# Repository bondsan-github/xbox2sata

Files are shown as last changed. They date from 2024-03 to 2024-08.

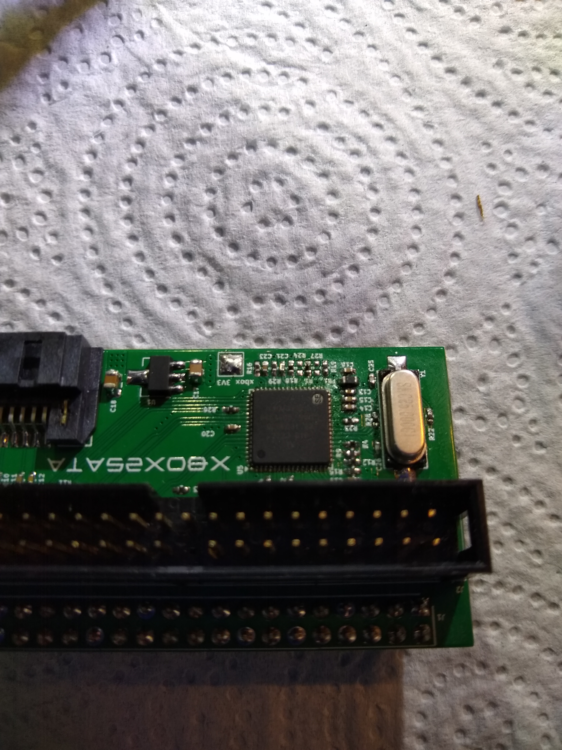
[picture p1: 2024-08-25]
Images/IMG_20240824_140959480.jpg

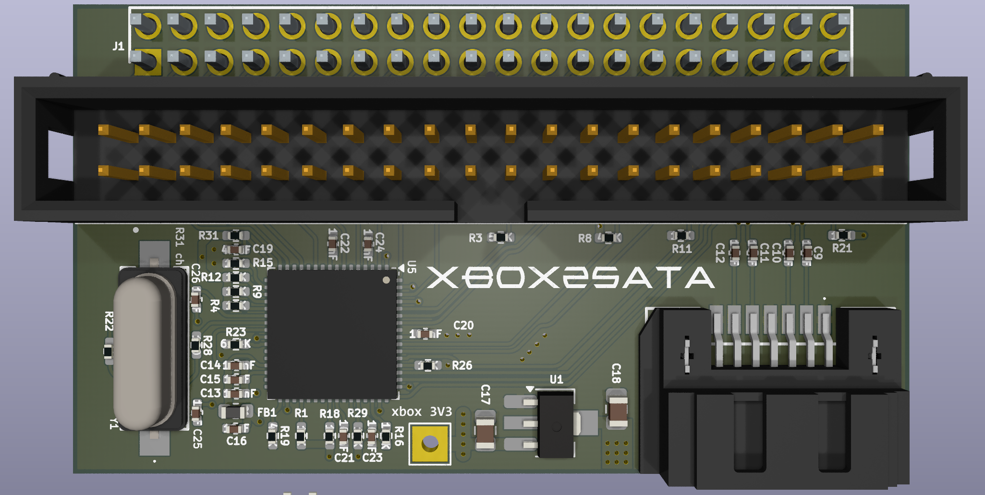
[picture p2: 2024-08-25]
Images/3d_render.png

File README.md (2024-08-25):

Aim
===
- Create a IDE to SATA bridge PCB with pass-through socket for XBox DVD cable.
- !3d render[3d render](/Images/3d_render.png)

Motivation
==========
- Remove the need for a 80 wire IDE cable
- Use existing IDE cable for DVD drive

Completed
=========
- Unverified schematic of Startech IDE2SATA pcb
- Startech IDE2SATA layer scans and annotations in GIMP .xcf image format.

To do
=====
Measure components;
- L1

- Find suitable 3V3 and ground points to tap on XBox motherboards
- Measure available space inside XBox under DVD drive.
  - there is/are a radial capacaitor/s close to the IDE header
    - I would like to not make a hole in the PCB for matched IDE to IDE routing lengths
    - The capactor/s have enough leg legnth to pull up and lay flat

- Can xbox ide connection be directly connected to DVD connection?
  - Simular how a IDE cable does?
  - IDE cable does have CSEL tied hi or low depending on device?
- Can LED circuit be removed? Is it for HDD activity?
- CSEL cable selection can be fixed as DVD will always be device 0 (slave) and SATA device 1 (master)?
- What capacitors are required for power input from xbox motherboard?

Requirements
============
- Marvell 88SA8052 - NNC2 IC
  -  PATA/ATAPI to SATA bridge chip W/ATAPI, 3 GBps SATA
     -  64 pin
     -  package: PQFN50P900X900X90-65
  - 1V2 Voltage regulator for Marvel IC Vdd
  - 3V3 for Marvel Vddio 
  - 25Mhz crystal oscillator
  - CNFG0,1,2 setup
  - T0,1,2,3,4,5,6,7,8 setup
  - will require 3V3 and ground solder points from all six motherboard revisions
    - 1.0 , 1.1 , 1.2 , 1.3 , 1.4 , 1.6/b

- xbox motherboard IDE socket
- DVD drive IDE header
- SATA to HDD/SATA socket

Desirables
==========
- Marvell 88SA8052 datasheet
- Connect pcb directly to xbox ide header on motherboard.
- Use motherboard 3V3 reducing one power regulator.
- Use existing IDE cable from pcb to dvd drive.
  - Cut or roll second connector behind dvd drive.
- Use power from existing molex connector to HDD/SSD.
  
Software used
=============
- GIMP 2.99.18 development release
- KiCad Schematic Editor 8.0.1
- Proteus 8.15 SP1
  
Sources
=======
- https://www.psdevwiki.com/ps3/88SA8040-TBC1
- https://consolemods.org/wiki/Xbox:Versions
- https://www.ioi.com.tw/products/proddetail.aspx?CatID=101&HostID=2010&DeviceID=3002&ProdID=1010114
- https://en.wikipedia.org/wiki/Parallel_ATA
- https://www.startech.com/en-gb/hdd/ide2sat2

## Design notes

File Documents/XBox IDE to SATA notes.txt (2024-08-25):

JM20330
88SA8040

http://www.dc-swat.ru/forum/printthread.php?tid=2482
Code:
pin 33 - T0          vendor ID (need PD 10 kOm)
pin 34 - T1          vendor ID/SATA LED# (need PU 10 kOm to VDD2 (3V3))
pin 35 - T2          PD: disable SSC     PU: enable SSC (int PD)
pin 36 - T3          clock speed     PD: 20MHz     PU: 25MHz    
pin 37 - T4          clock speed (need PD 10 kOm)
pin 38 - T5          fix UDMA mode     PD: monitor set feature     PU: fixes its UDMA mode
pin 39 - T6          power mode     PD: disable     PU: enable
pin 40 - T7          SATA mode     PD: 1.5 Gbps     PU: 3.0 Gbps
pin 52 - T8          SIGNATURE FIS     PD: transformer from registers     PU: force bit4 to 1

pin 18          pin 19          pin 20
CNFG0           CNFG1           CNFG2

  PD              PD               PD          Device mode 100 MB/s
  PU              PD               PD          Device mode 133 MB/s
  PD              PU               PD          Device mode 150 MB/s
  PD              PU               PU          Host mode 150 MB/s

*PD - pool down (connect to GND over resistor 10 kOm)
*PU - pool up (connect to VCC2(3.3 V) over resistor 10 kOm)

FB1 psdevwiki BLM11P600S; no longer manufactured, replaced with BLM18PG600SN1D

https://www.mouser.co.uk/ProductDetail/Murata-Electronics/BLM18PG600SN1D?qs=LbqjZSvnDsxC2SXhhViR%252BA%3D%3D

IDE to Marvell IC
=================
1  (RESET-) 16
2  GND
3  (DD7)  15
4  (DD8)  14
5  (DD6)  13
6  (DD9)  12
7  (DD5)  11
8  (DD10) 10
9  (DD4)  7
10 (DD11) 6
11 (DD3)  5
12 (DD12) 3
13 (DD2)  2
14 (DD13) 1
15 (DD1)  64
16 (DD14) 63
17 (DD0)  62
18 (DD15) 61
19 GND
20 KEY PIN
21 (DMARQ) 60
22 GND
23 (DIOW-) 59
24 GND
25 (DIOR-) 58
26 GND
27 (IORDY) 55
28 (CSEL) -> jumpers pin 1 & pin 2 -> R14 -> 3V3 
29 (DMACK-) 54
30 GND
31 (INTRQ) 53
32 (IOCS16) -> R13 -> GND
33 (DA1) 51
34 (PDIAG-) 
35
36
37
38
39
40 GND

Jumper
======
1 & 2 = cable select
3 & 4 = Slave
5 & 6 = Master
7 & 8 = DCA

pin 2 -> U5 pin 33 (T0)
pin 1 -> IDE pin 28

pin 3 -> U5 pin 33 (T0)
pin 4 -> R10 -> GND

pin 6 -> U5 pin 33 (T0)
pin 5 -> R19 -> GND

pin 7 -> R25 -> U5 pin 38
pin 8 -> 3v3

t0, U5 33 -> jumper 2 & 3 & 6
t1, U5 34 -> ide pin 39
t2, U5 35 -> r27 -> 3v3
t3, U5 36 -> r1 -> 3v3
t4, U5 37 -> GND
t5, U5 38 -> r25 -> jumper 7 ( DCA ) ( floating )
t6, U5 39 -> r24 -> 3v3
t7, U5 40 -> r18 -> 3v3
t8, U5 52 -> r26 -> GND

U1
==
613233GP PM67B, Package SOT-89-3  = FP6132
https://www.ebastlirna.cz/modules.php?name=Forums&file=viewtopic&p=1299356&highlight=#1299356

Voltages from version 1.4 motherboard
=====================================
3V3, signal name V_1P5 , connect to DB_7F1 @ top F8 ( close to radial capacitor C7E2, 1500uF 6.3v )

Voltages from version 1.1 motherboard
=====================================
pdf page 33
VCC3

2V5, signal name V_2P5, DB6F1

Aim
===
Create a IDE to SATA bridge PCB with pass-through socket for XBox DVD cable. 

Sources
=======
https://www.psdevwiki.com/ps3/88SA8040-TBC1
https://www.ioi.com.tw/products/proddetail.aspx?CatID=101&HostID=2010&DeviceID=3002&ProdID=1010114
https://en.wikipedia.org/wiki/Parallel_ATA
https://www.startech.com/en-gb/hdd/ide2sat2

Completed
=========
Unverified schematic of Startech IDE2SATA pcb

To do
=====
Marvell 88SA8052 requires; -NNC2
1V2 for Vdd
3V3 for Vddio and pull-ups

Measure components;
L1
R5
R6

Find suitable 5V and ground points to tap on XBox motherboard.

Measure available space inside XBox under DVD drive.

Software used
=============
Proteus 8.15 SP1
GIMP 2.99.18 development release

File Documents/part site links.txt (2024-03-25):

SATA data port
==============

https://www.mouser.co.uk/ProductDetail/Molex/67800-8025?qs=3DzawVMofg92QkpdTaH6sA%3D%3D

https://www.digikey.co.uk/en/products/filter/pluggable-connectors/pluggable-connector-assemblies/443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

DVD drive IDE header
====================

https://www.mouser.co.uk/ProductDetail/Wurth-Elektronik/61203921621?qs=PhR8RmCirEbpHRYxpUyjEw%3D%3D

https://www.digikey.co.uk/en/products/detail/te-connectivity-amp-connectors/1761633-2/1122038

https://www.digikey.co.uk/en/products/filter/rectangular-connectors/headers-male-pins/314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

XBox IDE socket
===============

https://www.mouser.co.uk/ProductDetail/Molex/90151-2140?qs=WjPO6T6WDwtb8fg%2FDgSCUQ%3D%3D

https://www.mouser.co.uk/c/connectors/headers-wire-housings/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

https://www.digikey.co.uk/en/products/filter/rectangular-connectors/headers-receptacles-female-sockets/315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

Crystal 25 MHz
==============

https://www.mouser.co.uk/ProductDetail/ABRACON/ABLS-25.000MHZ-B4-F-T?qs=yTU0IcKoRlHGW93axwFkQw%3D%3D

1V2 voltage regulator
=====================

https://www.mouser.co.uk/ProductDetail/Texas-Instruments/TLV1117LV12DCYR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

Qty.	Unit Price	
1	£0.32

TLV1117LV12DCYR
SOT-223-4

Output Voltage:	1.2 V	
Output Current:	1 A	
Number of Outputs: 1 Output	
Polarity: Positive	
Quiescent Current: 100 uA	
Input Voltage, Min: 2 V	
Input Voltage, Max: 5.5 V	
Output Type: Fixed	
Minimum Operating Temperature: - 40 C
Maximum Operating Temperature: + 125 C
Dropout Voltage: 570 mV

1uF MLC capacitor
=================

https://www.mouser.co.uk/ProductDetail/TDK/C1608X7R1A105K080AC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

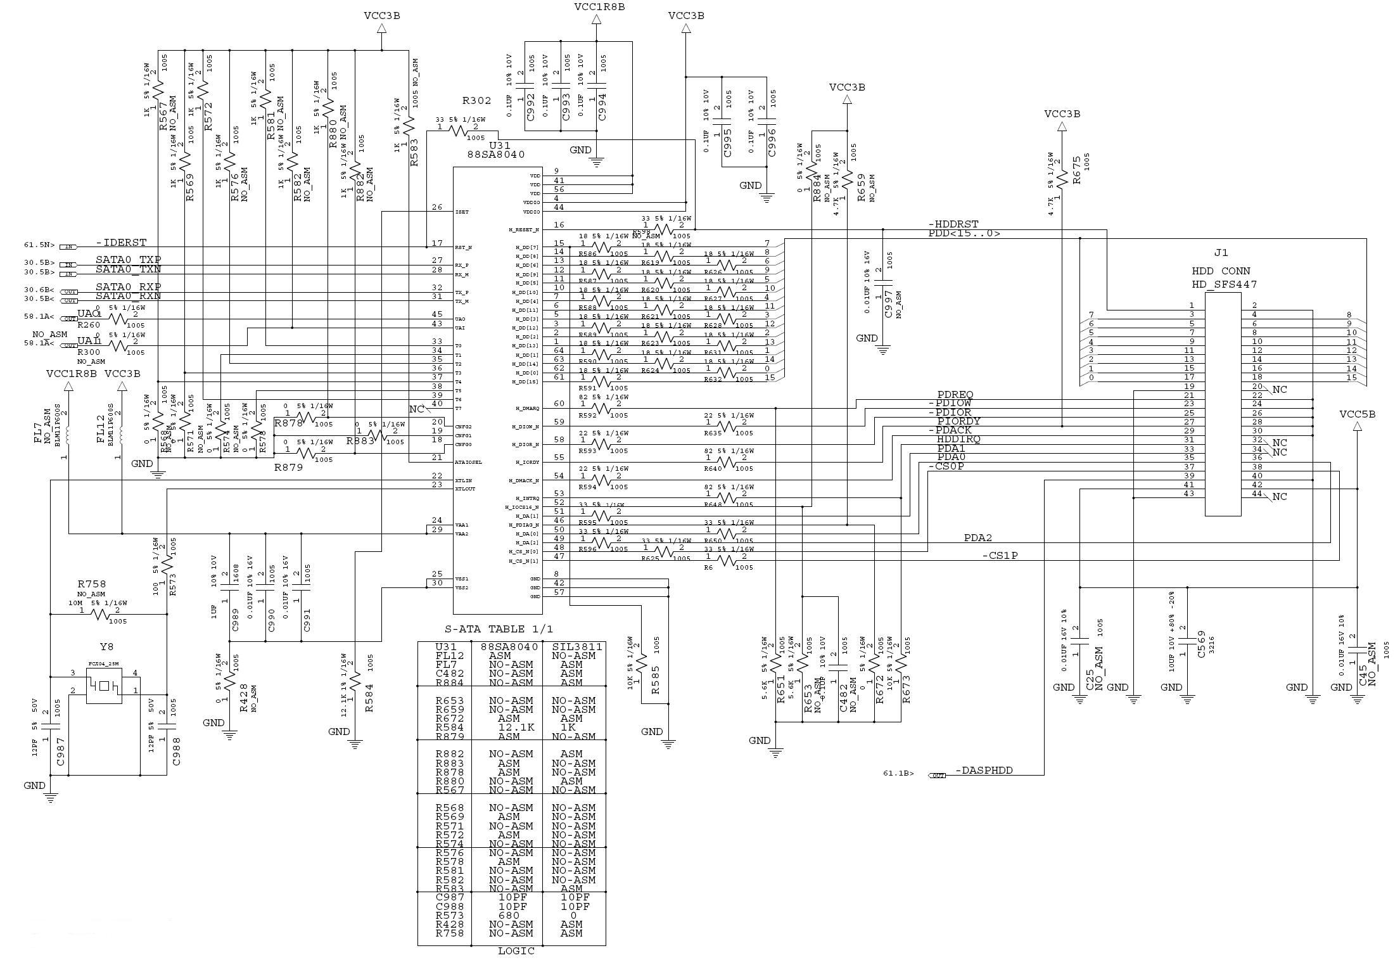
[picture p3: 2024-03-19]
Images/Marvell_88SA8040-TBC1-pinout.jpg

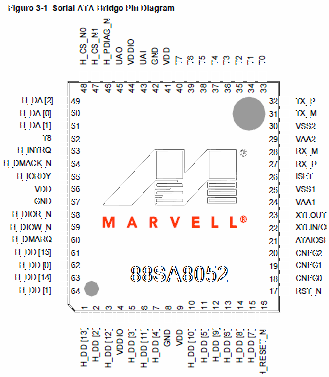
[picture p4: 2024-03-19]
Images/Marvell_88SA8052-pinout.png

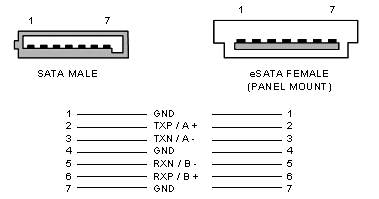
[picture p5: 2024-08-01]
Images/sata socket pinout.gif

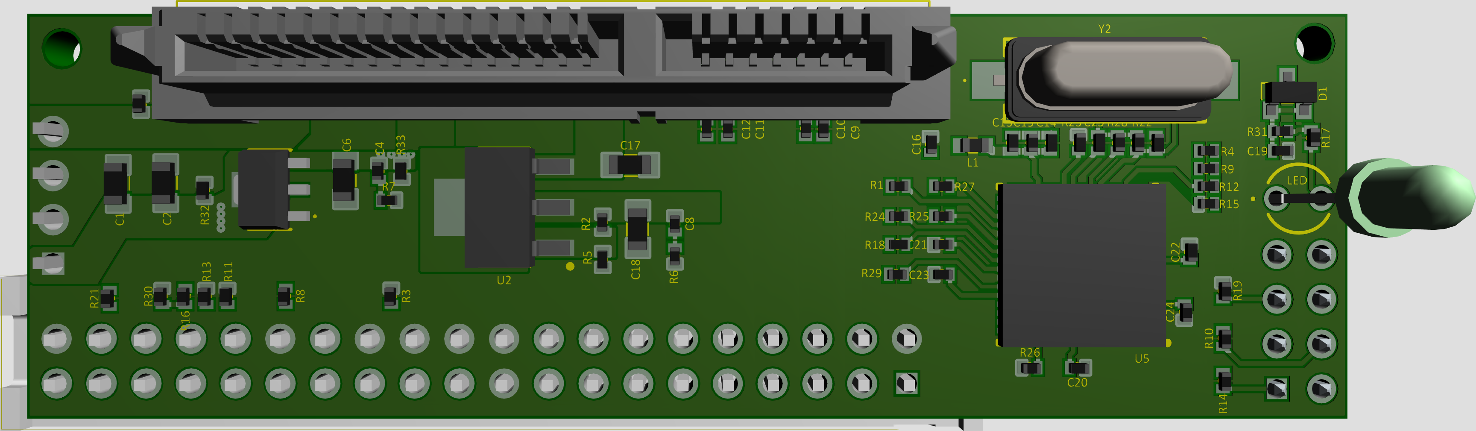
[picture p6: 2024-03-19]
Images/Startech 3D view top.png

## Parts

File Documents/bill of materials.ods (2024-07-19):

Reference / label | Category | Description | Package | Value | Manufacturer | Part number | Quantity | Unit cost | Web link | Notes
J1 | Connector | IDE female socket | RHDR40W76P254_2X20_5080X508X826P | 929975-01-20-RK | 3M | 929975-01-20-RK | 1 | £2.440 | https://www.mouser.co.uk/ProductDetail/3M-Electronic-Solutions-Division/929975-01-20-RK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
J2 | Connector | IDE male header | 61203921621 | 61203921621 | Wurth Elektronik | 61203921621 | 1 | £1.080 | https://www.mouser.co.uk/ProductDetail/Wurth-Elektronik/61203921621?qs=PhR8RmCirEbpHRYxpUyjEw%3D%3D
J3 | Connector | SATA socket | SATAAPLSMTK | SATA-A-PL-SMT-K | Adam Tech | SATA-A-PL-SMT-K | 1 | £0.740 | https://www.mouser.co.uk/ProductDetail/Adam-Tech/SATA-A-PL-SMT-K?qs=HoCaDK9Nz5dztr92%2FSCAMw%3D%3D
U1 | Voltage regulator | LDO | SOT-89 | LDI1117-1.2U | Diotec Semiconductor | LDI1117-1.2U | 1 | £0.140 | https://www.mouser.co.uk/ProductDetail/Diotec-Semiconductor/LDI1117-1.2U?qs=OlC7AqGiEDkwgXd1Nm4KeQ%3D%3D
U5 | Integrated circuit | IDE to SATA bridge | QFN-64-1EP_9x9mm_P0.5mm_EP3.4x3.4mm_ThermalVias | 88SA8052-NNC2 | Marvell | 88SA8052-NNC2 | 1 | £3.650 | https://www.aliexpress.com/item/1005005930315915.html
Y1 | Crystal | Crystal | 11.4 x 4.7 x 4.2 mm | 25Mhz, 16pF, 40Ω | ABRACON | ABLS-25.000MHZ-16-A-4-H-F-T | 1 | £0.150 | https://www.mouser.co.uk/ProductDetail/ABRACON/ABLS-25.000MHZ-16-A-4-H-F-T?qs=vLWxofP3U2wYSEjvdJ0sYQ%3D%3D
C17, C18 | Capacitor | SMD Capacitor | 0805 | 10µF | TAIYO YUDEN | JMK212ABJ106KG-T | 2 | £0.079 | https://www.mouser.co.uk/ProductDetail/TAIYO-YUDEN/JMK212ABJ106KG-T?qs=GTwwGWkfii0MOm5EE9mfVw%3D%3D | Tolerance: 10 %
C9, C10, C11, C12, C16, C15 | Capacitor | SMD Capacitor | 0402 | 10nF | Vishay / Vitramon | VJ0402Y103JXQCW1BC | 6 | £0.036 | https://www.mouser.co.uk/ProductDetail/Vishay-Vitramon/VJ0402Y103JXQCW1BC?qs=ihJ2iVknB9tTia%2FLlcEf6A%3D%3D | Tolerance: 5 %
C13, C14, C20, C21, C22, C23, C24 | Capacitor | SMD Capacitor | 0402 | 100nF | Walsin | 0402B104J100CT | 7 | £0.018 | https://www.mouser.co.uk/ProductDetail/791-0402B104J100CT | Tolerance: 5 %
C19 | Capacitor | SMD Capacitor | 0402 | 4.7µF | Samsung Electro-Mechanics | CL05A475KQ5NRNC | 1 | £0.079 | https://www.mouser.co.uk/ProductDetail/Samsung-Electro-Mechanics/CL05A475KQ5NRNC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 | Tolerance: 10 %
C25, C26 | Capacitor | SMD Capacitor | 0402 | 16pF | YAGEO | CC0402GRNPO9BN160 | 2 | £0.080 | https://www.mouser.co.uk/ProductDetail/YAGEO/CC0402GRNPO9BN160?qs=r5DSvlrkXmJbEhY6l9xNOQ%3D%3D | Tolerance: 2 %, adjust Value according to used crystal
FB1 | Ferrite bead | SMD Ferrite bead | 0603 | 120Ω, 100Mhz, 2A | Walsin | WQBD1608HCU121TH | 1 | £0.092 | https://www.mouser.co.uk/ProductDetail/Walsin/WQBD1608HCU121TH | Tolerance: 25 %
R3, R31 | Resistor | SMD Resistor | 0402 | 5.6KΩ | TE Connectivity / Holsworthy | CRGCQ0402F5K6 | 2 | £0.079 | https://www.mouser.co.uk/ProductDetail/TE-Connectivity-Holsworthy/CRGCQ0402F5K6 | Tolerance: 1 %
R4, R9, R11, R12, R14, R15, R18, R21, R24, R26, R29 | Resistor | SMD Resistor | 0402 | 10KΩ | Panasonic | ERJ-2RHD103X | 11 | £0.079 | https://www.mouser.co.uk/ProductDetail/Panasonic/ERJ-2RHD103X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 | Tolerance: 0.5 %
R23 | Resistor | SMD Resistor | 0402 | 6.04KΩ | YAGEO | RT0402DRE076K04L | 1 | £0.079 | https://www.mouser.co.uk/ProductDetail/YAGEO/RT0402DRE076K04L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 | Tolerance: 0.5 %
R1, R8, R19, R27 | Resistor | SMD Resistor | 0402 | 4.7KΩ | YAGEO | RC0402FR-7W4K7L | 4 | £0.079 | https://www.mouser.co.uk/ProductDetail/YAGEO/RC0402FR-7W4K7L | Tolerance: 1 %
R22 | Resistor | SMD Resistor | 0402 | 1MΩ | YAGEO | RC0402FR-071MP | 1 | £0.079 | https://www.mouser.co.uk/ProductDetail/YAGEO/RC0402FR-071MP | Tolerance: 1 %
R28 | Resistor | SMD Resistor | 0402 | 100Ω | YAGEO | RC0402FR-7W100RL | 1 | £0.079 | https://www.mouser.co.uk/ProductDetail/YAGEO/RC0402FR-7W100RL | Tolerance: 1 %
R16 | Resistor | SMD Resistor | 0402 | 100KΩ | Wurth Elektronik | 560112110019 | 1 | £0.079 | https://www.mouser.co.uk/ProductDetail/Wurth-Elektronik/560112110019 | Tolerance: 1 %
External | Cable | MOLEX LP4 4 pin to SATA 15 pin power adapter |  |  | Advantech | 1700018785 | 1 | £2.060 | https://www.mouser.co.uk/ProductDetail/Advantech/1700018785?qs=dawwGz1r7uZfJNDNJFd1BQ%3D%3D
External | Cable | SATA HDD data cable |  |  | Advantech | 1700003194 | 1 | £2.610 | https://www.mouser.co.uk/ProductDetail/Advantech/1700003194?qs=dawwGz1r7uYoUmZ19BNkcg%3D%3D

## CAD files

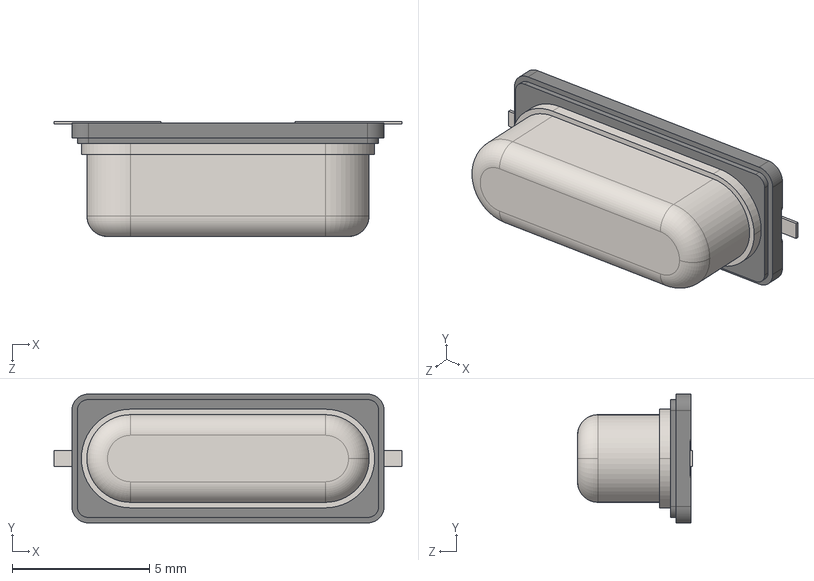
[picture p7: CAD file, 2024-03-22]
PCB/KiCad/Imports/Crystal/ABLS-25.000MHZ-B4-F-T.stp
12.7 x 4.70 x 4.20 mm

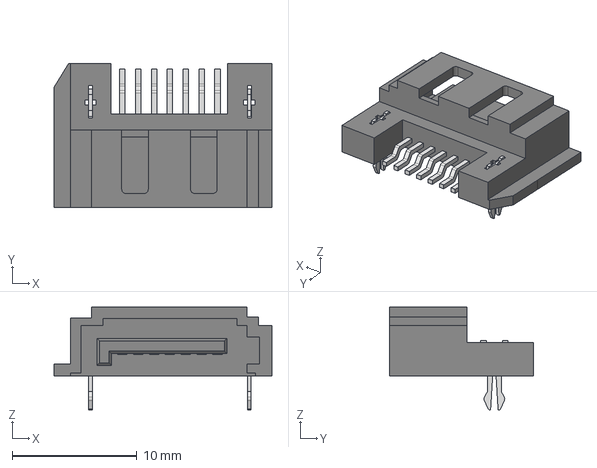
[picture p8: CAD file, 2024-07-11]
PCB/KiCad/Imports/SATA socket/SATA-A-PL-SMT-K.stp
17.5 x 11.5 x 8.23 mm

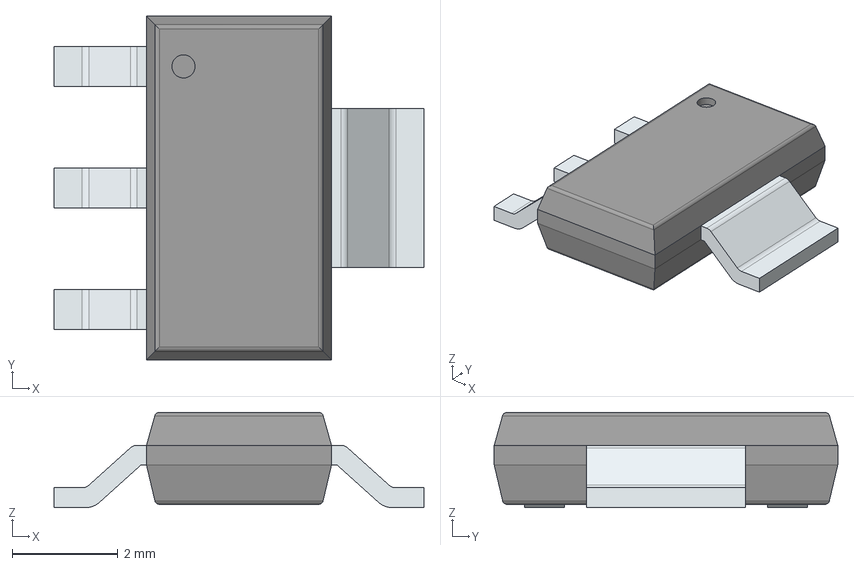
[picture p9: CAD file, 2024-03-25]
PCB/KiCad/Imports/TLV1117LV12DCYR/3D/TLV1117LV12DCYR.stp
7.00 x 6.50 x 1.80 mm
PinsArrayL
FilletPinR

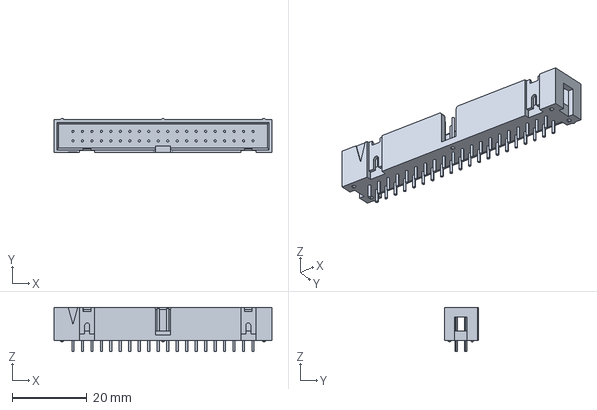
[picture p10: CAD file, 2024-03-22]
PCB/KiCad/Imports/1761633-2.stp
58.4 x 9.22 x 11.8 mm

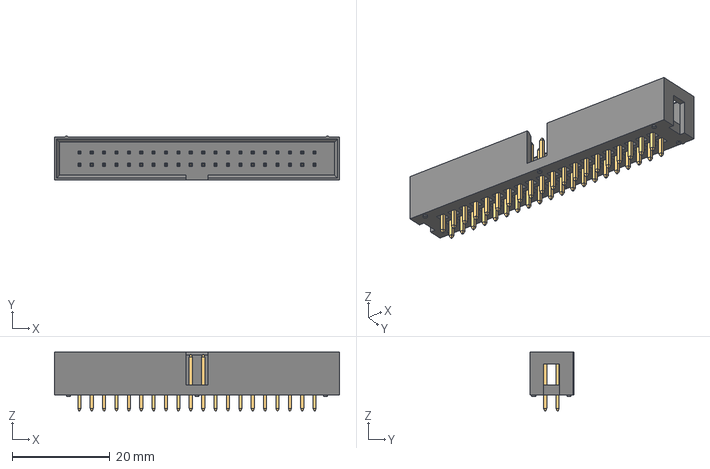
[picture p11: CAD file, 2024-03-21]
PCB/KiCad/Imports/IDE header/61203921621_Download_IGS_61203921621_rev1.igs
58.5 x 9.10 x 12.1 mm

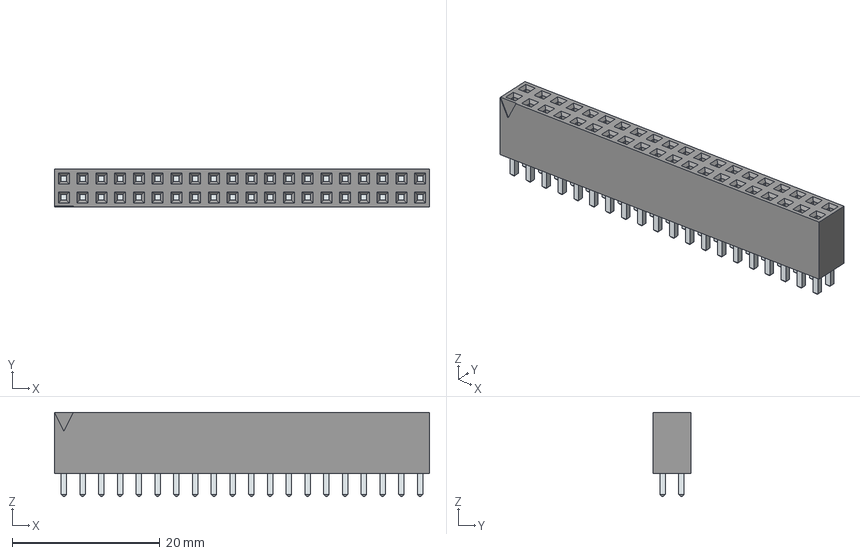
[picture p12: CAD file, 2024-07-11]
PCB/KiCad/Imports/IDE socket/929975-01-20-RK/929975-01-20-RK.stp
50.8 x 5.08 x 11.4 mm
LeadsArray

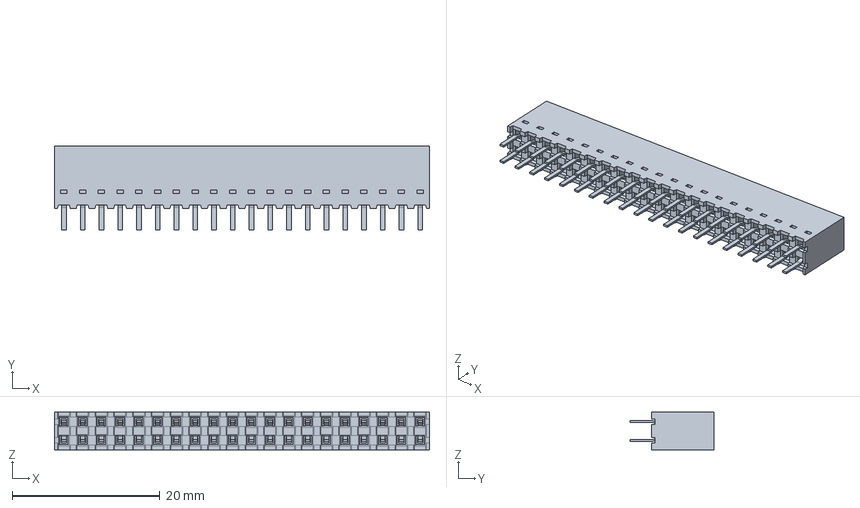
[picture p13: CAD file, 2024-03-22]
PCB/KiCad/Imports/Molex 90151-2140 KiCad/90151-2140.stp
50.8 x 11.4 x 5.08 mm

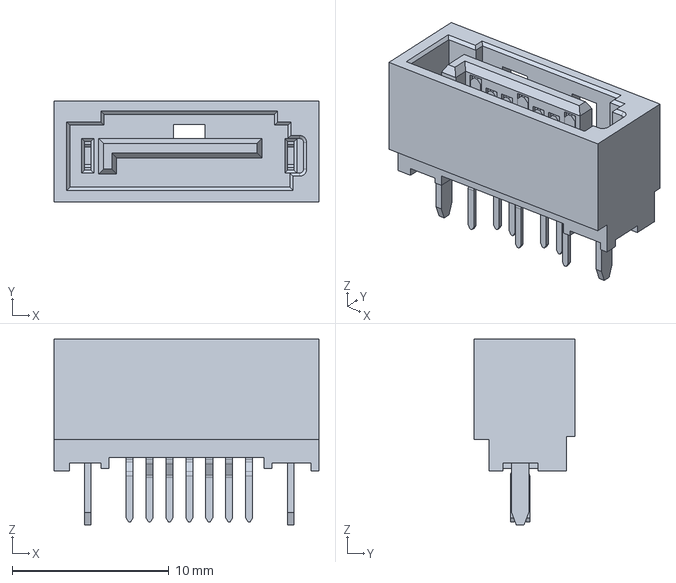
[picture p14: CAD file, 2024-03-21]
PCB/KiCad/Imports/678008025.stp
16.9 x 6.45 x 11.9 mm

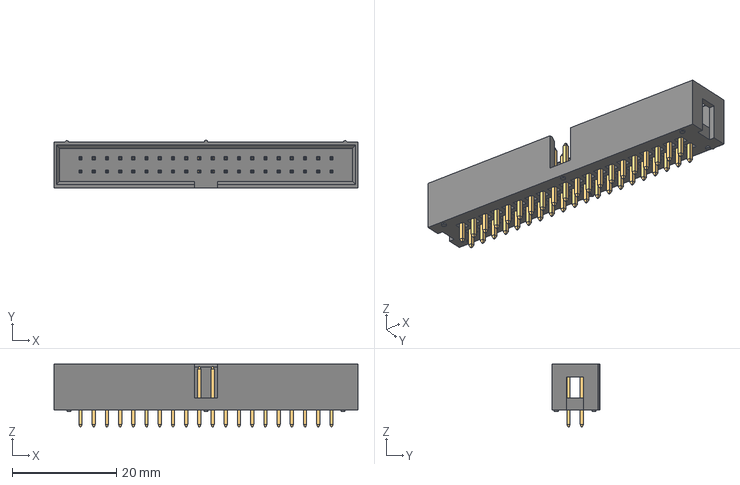
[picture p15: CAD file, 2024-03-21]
PCB/KiCad/Imports/IDE header/61203921621_Download_STP_61203921621_rev1.stp
58.5 x 9.18 x 12.1 mm
6120xx21621_PIN x 40

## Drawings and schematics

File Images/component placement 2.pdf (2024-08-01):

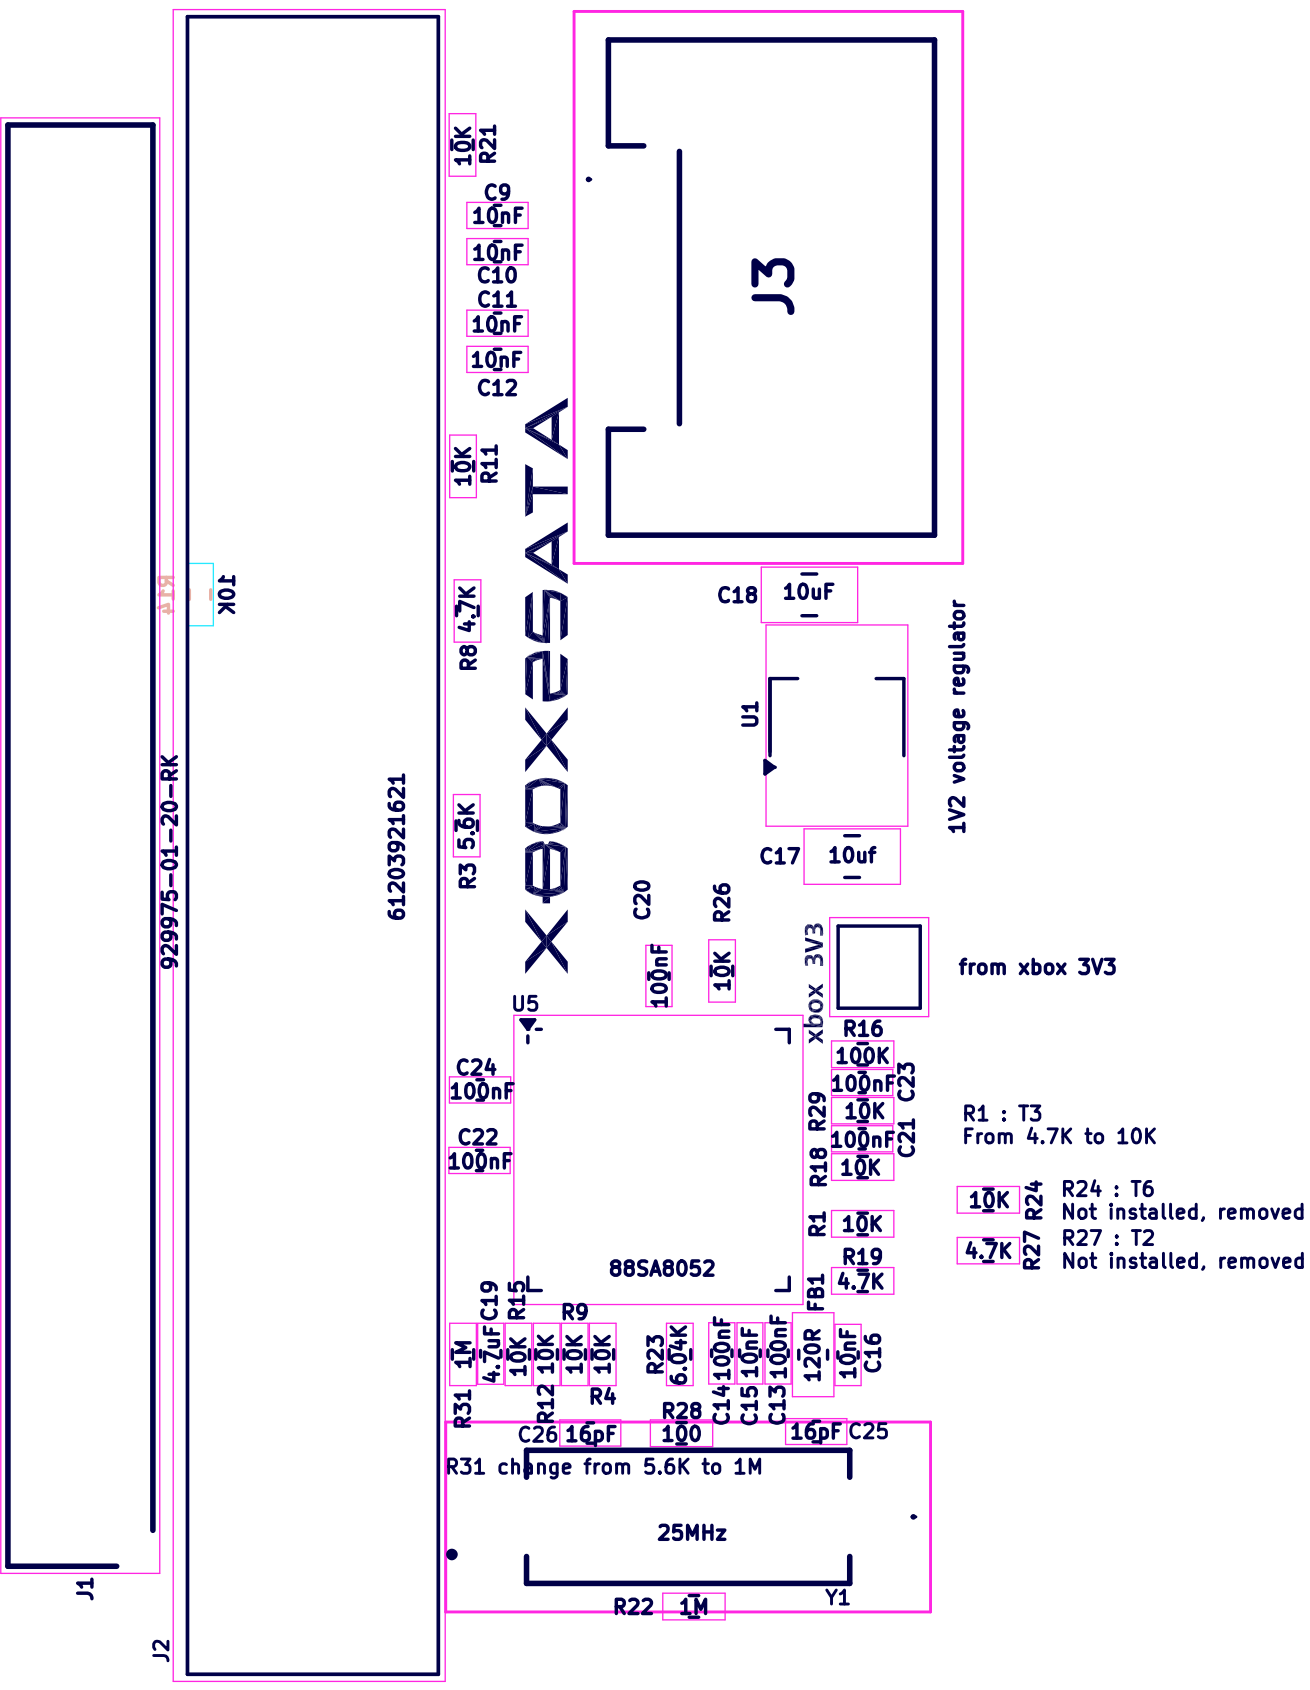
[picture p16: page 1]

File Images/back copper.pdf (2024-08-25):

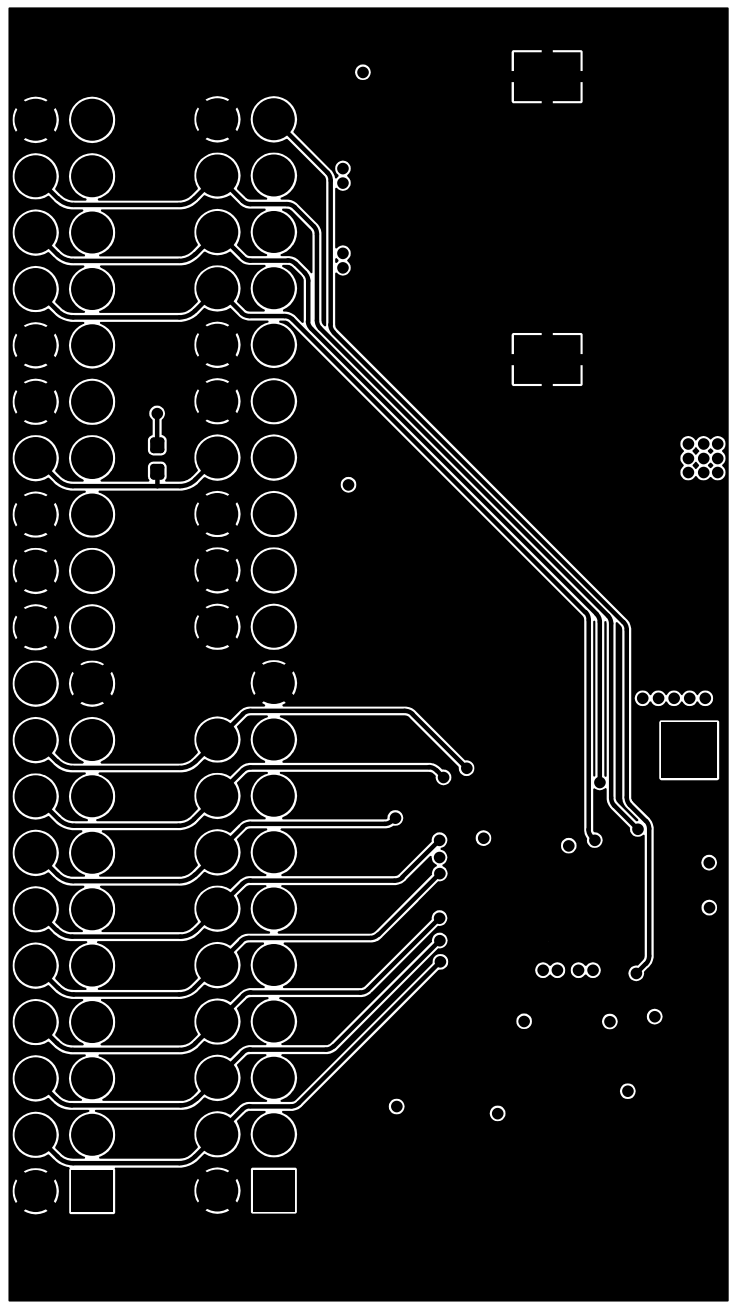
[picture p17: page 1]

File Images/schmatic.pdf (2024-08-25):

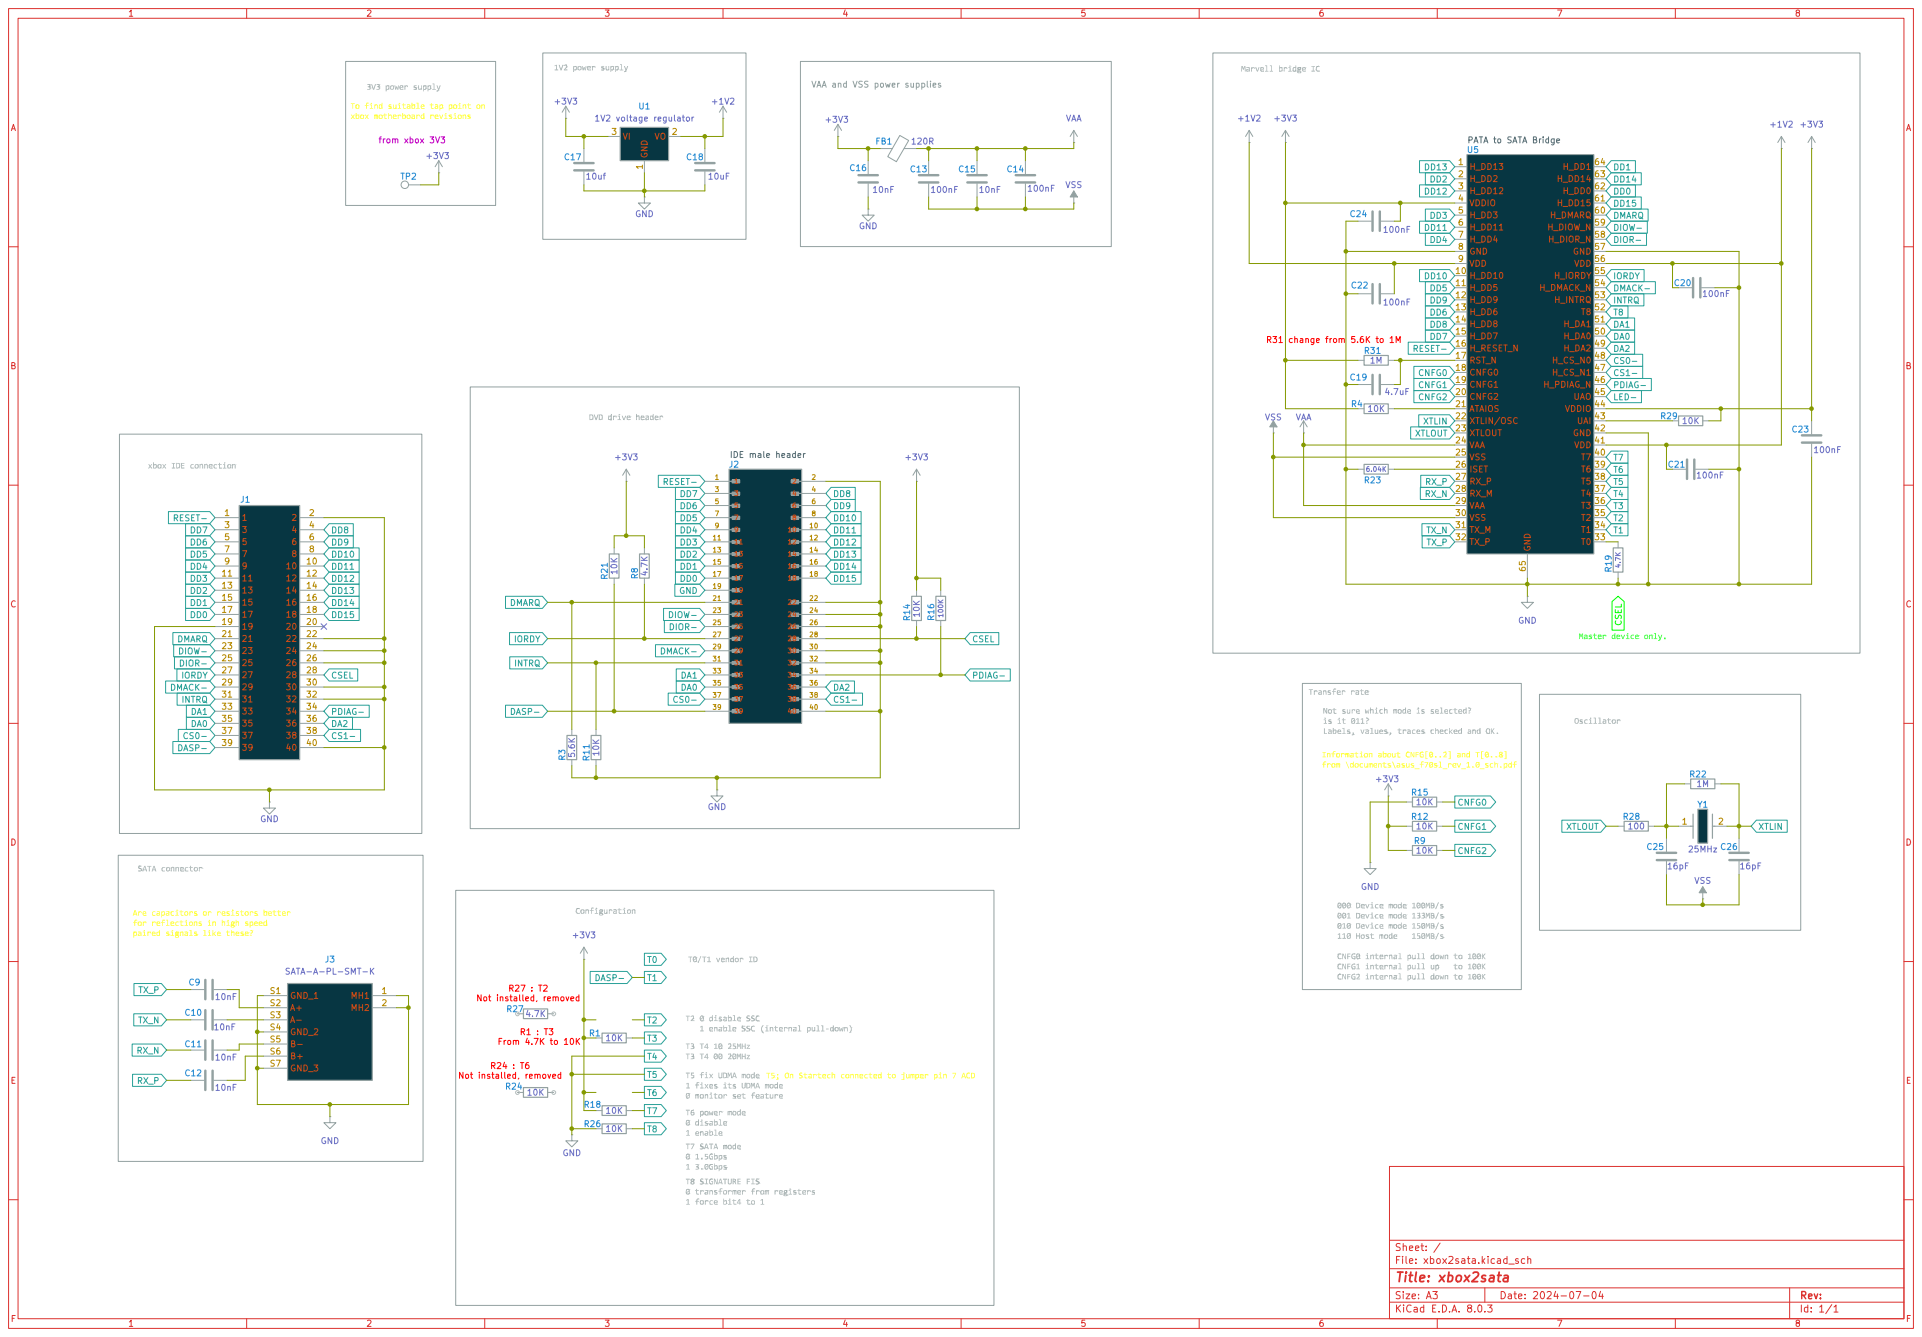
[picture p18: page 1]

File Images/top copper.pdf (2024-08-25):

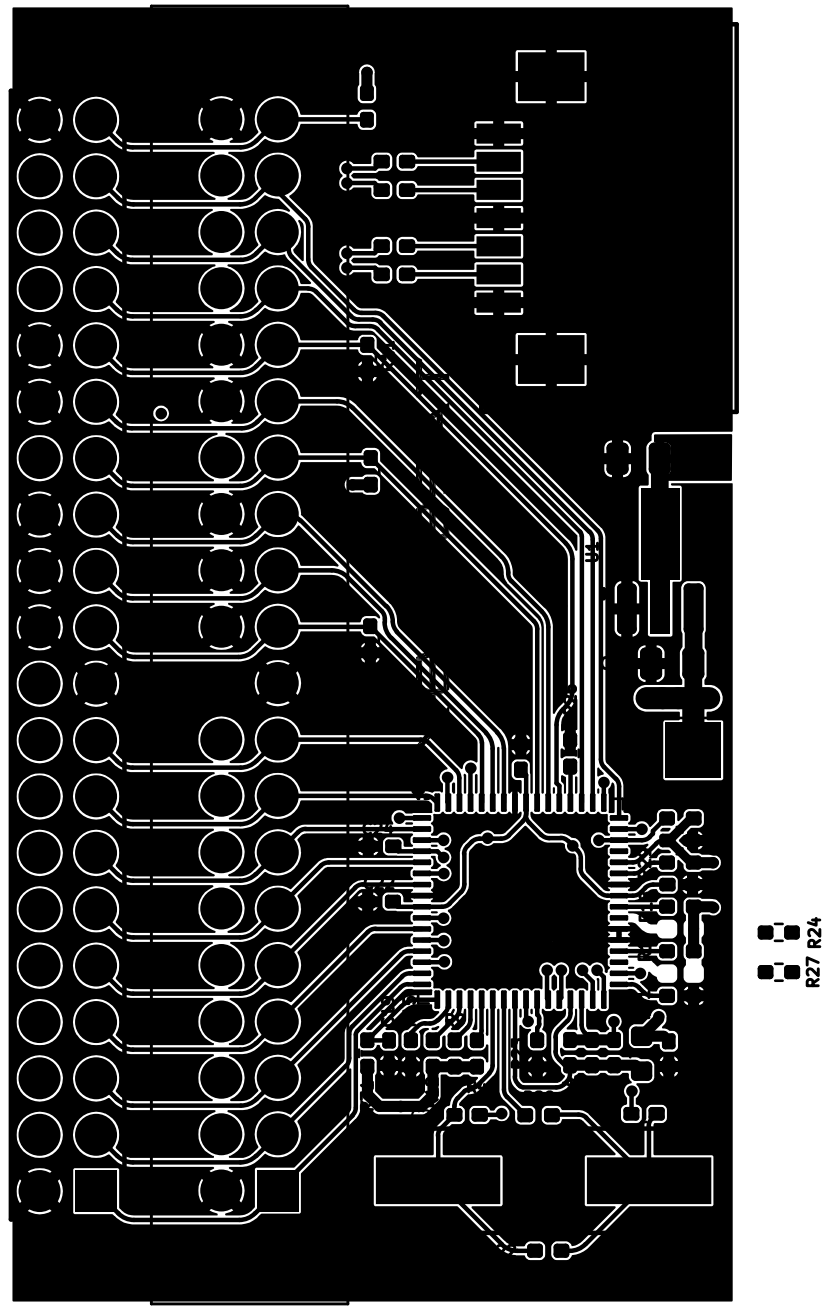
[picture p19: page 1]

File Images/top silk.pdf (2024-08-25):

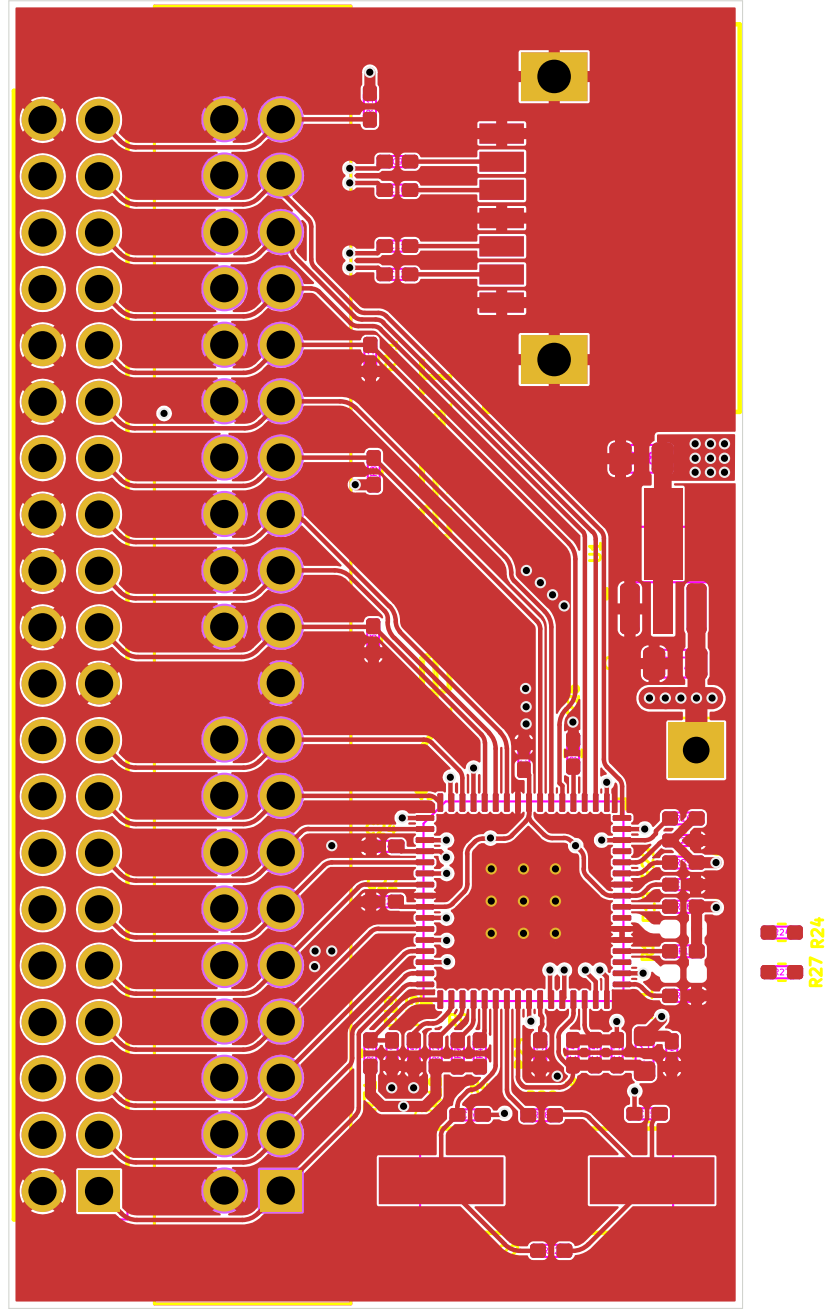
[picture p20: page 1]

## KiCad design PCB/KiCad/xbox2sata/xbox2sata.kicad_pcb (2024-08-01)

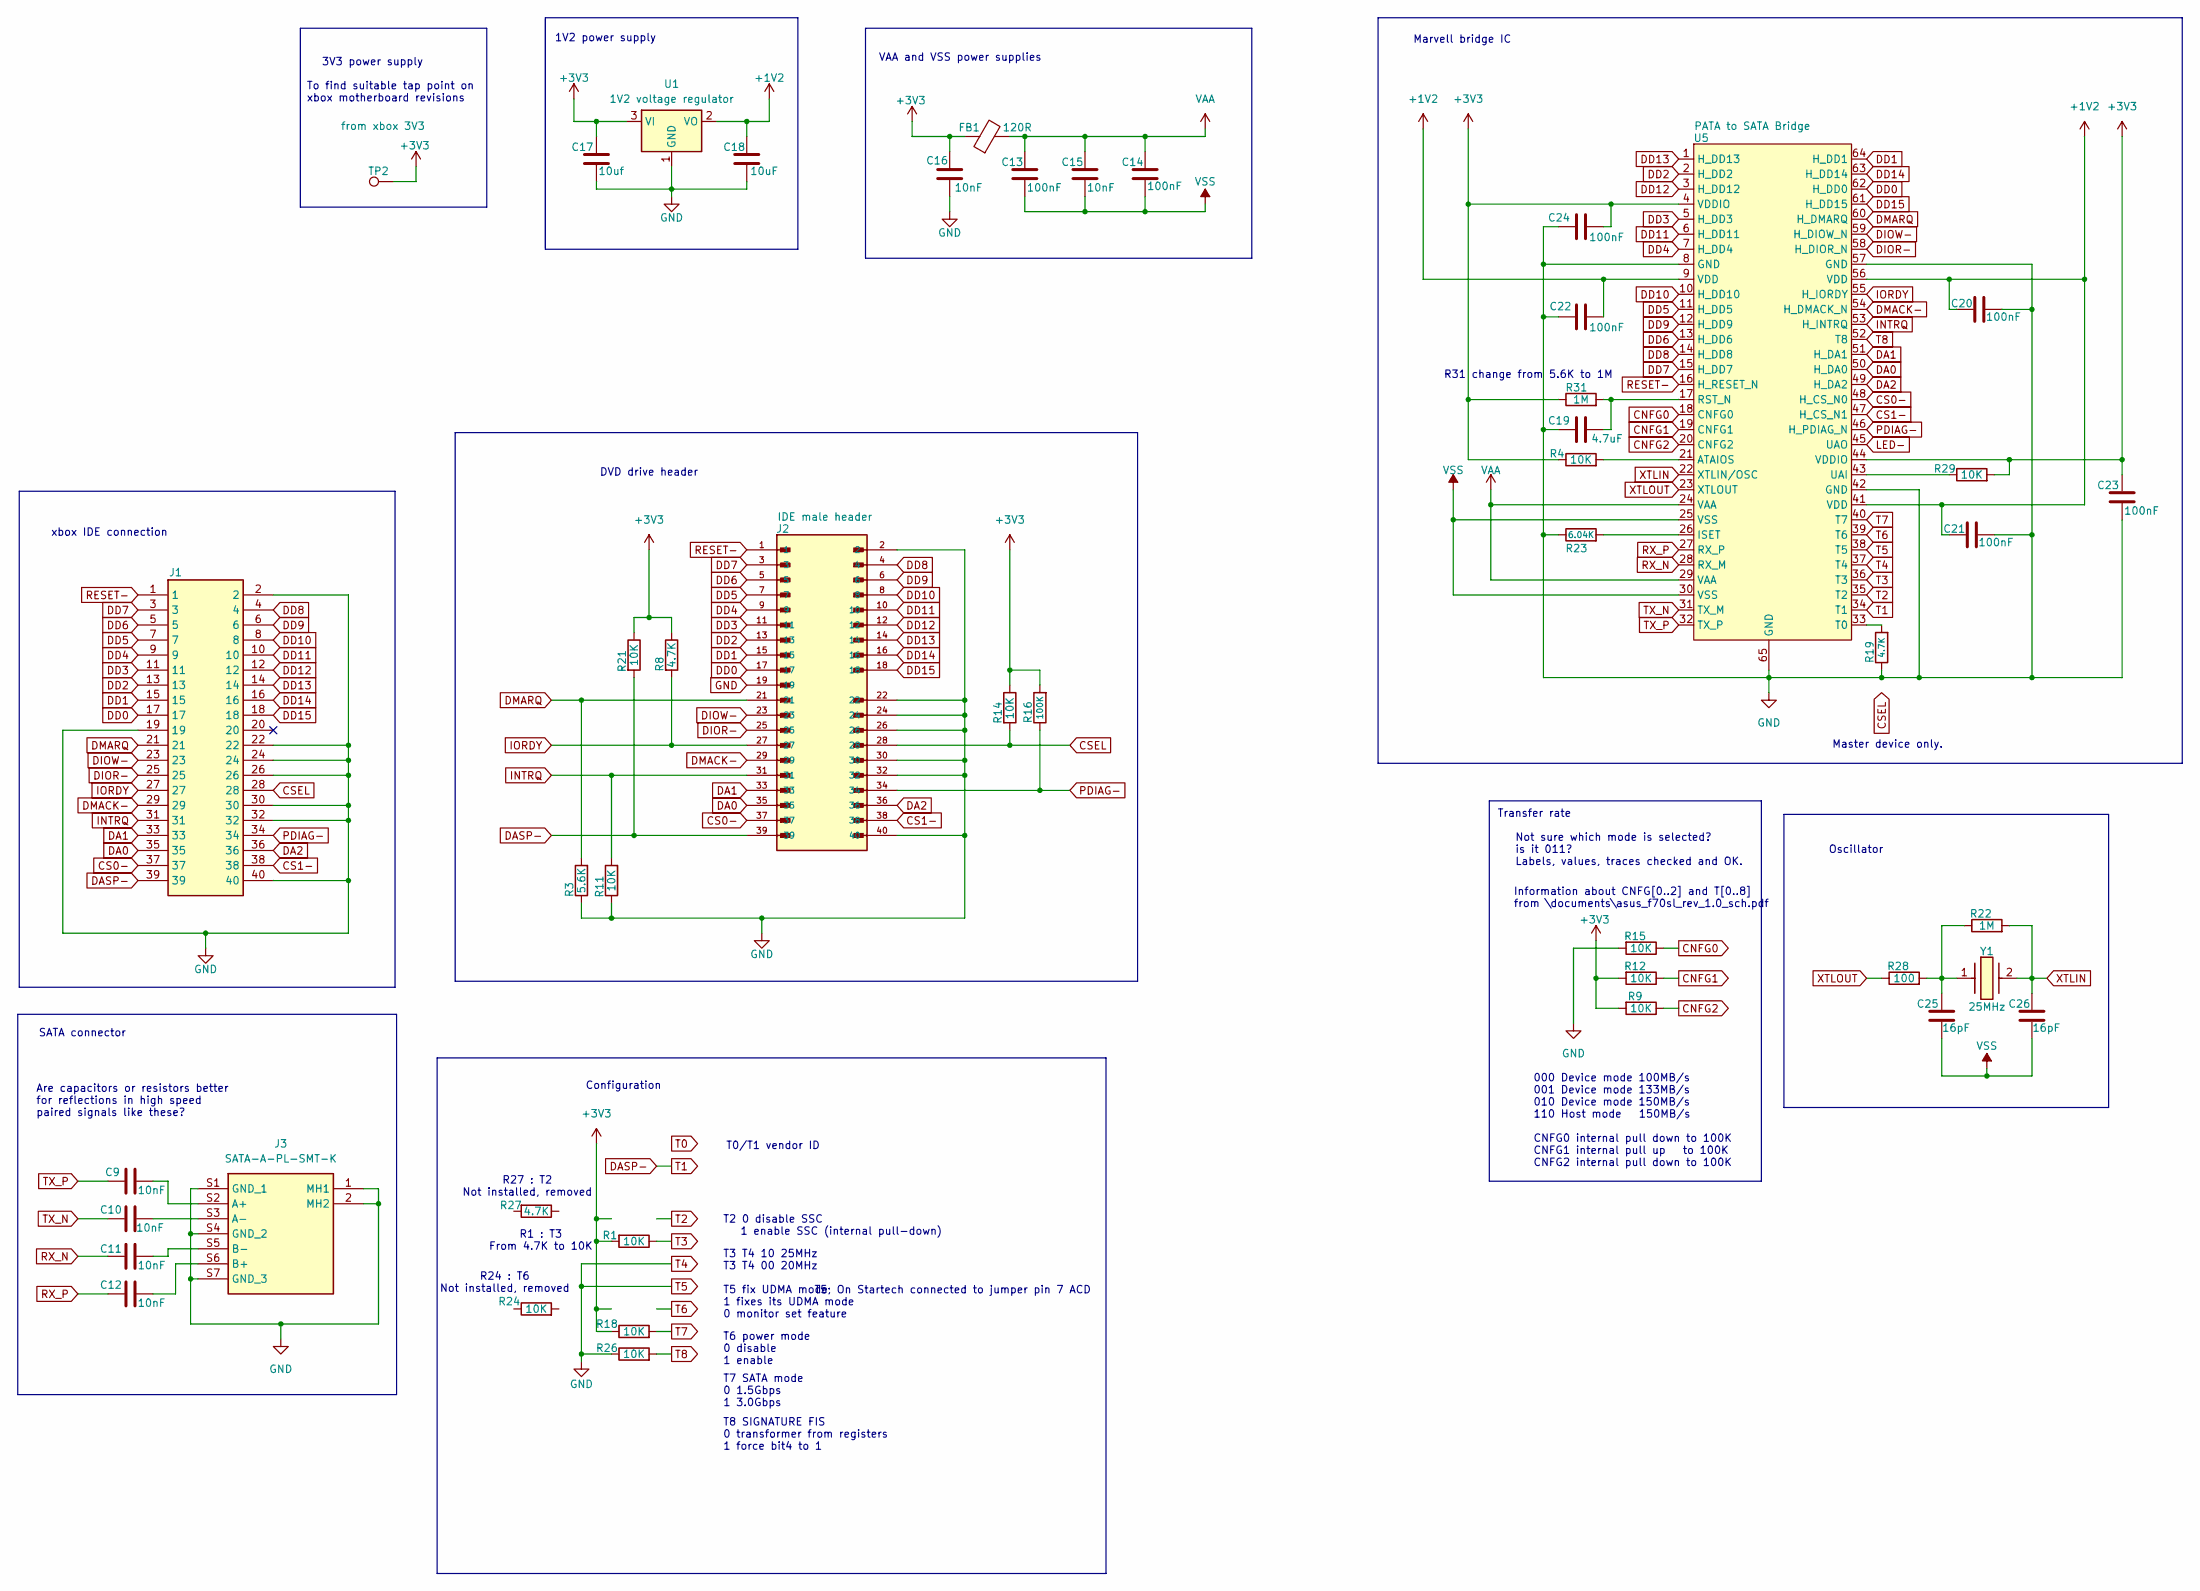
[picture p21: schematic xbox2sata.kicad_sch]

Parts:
C9, C10, C11, C12, C15, C16: 10nF; C_0402_1005Metric_Pad0.74x0.62mm_HandSolder
C13, C14, C20, C21, C22, C23, C24: 100nF; C_0402_1005Metric_Pad0.74x0.62mm_HandSolder
C17: 10uf; C_0805_2012Metric
C18: 10uF; C_0805_2012Metric
C19: 4.7uF; C_0402_1005Metric_Pad0.74x0.62mm_HandSolder
C25, C26: 16pF; C_0402_1005Metric_Pad0.74x0.62mm_HandSolder
FB1: 120R; L_0603_1608Metric; Current rating 2A
J1: 929975-01-20-RK; RHDR40W76P254_2X20_5080X508X826P; Mouser Part Number 517-929975-01-20-RK
J2: 61203921621; WURTH-ELEKTRONIK_61203921621; PARTREV 002.000
J3: SATA-A-PL-SMT-K; SATAAPLSMTK; Mouser Part Number 737-SATA-A-PL-SMT-K
R1, R4, R9, R11, R12, R14, R15, R18, R21, R24, R26, R29: 10K; R_0402_1005Metric_Pad0.72x0.64mm_HandSolder
R3: 5.6K; R_0402_1005Metric_Pad0.72x0.64mm_HandSolder
R8, R19, R27: 4.7K; R_0402_1005Metric_Pad0.72x0.64mm_HandSolder
R16: 100K; R_0402_1005Metric_Pad0.72x0.64mm_HandSolder
R22, R31: 1M; R_0402_1005Metric_Pad0.72x0.64mm_HandSolder
R23: 6.04K; R_0402_1005Metric_Pad0.72x0.64mm_HandSolder
R28: 100; R_0402_1005Metric_Pad0.72x0.64mm_HandSolder
TP2: from xbox 3V3; TestPoint_THTPad_2.5x2.5mm_Drill1.2mm
U1: 1V2 voltage regulator; SOT-89-3_Handsoldering
U5: 88SA8052; QFN-64-1EP_9x9mm_P0.5mm_EP3.4x3.4mm_ThermalVias
Y1: 25MHz; Crystal; Mouser Part Number 815-ABLS25MHZ16A4HFT

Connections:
+1V2: C18.1, C20.1, C21.1, C22.2, U1.2 (VO), U5.9 (VDD), U5.41 (VDD), U5.56 (VDD)
+3V3: C16.1, C17.2, C23.1, C24.2, FB1.1, R1.2, R4.1, R8.1, R9.2, R12.2, R14.1, R16.2, R18.1, R21.1, R29.2, R31.1, TP2.1, U1.3 (VI), U5.4 (VDDIO), U5.44 (VDDIO)
CNFG0: R15.1, U5.18 (CNFG0)
CNFG1: R12.1, U5.19 (CNFG1)
CNFG2: R9.1, U5.20 (CNFG2)
CS0-: J1.37, J2.37, U5.48 (H_CS_N0)
CS1-: J1.38, J2.38, U5.47 (H_CS_N1)
CSEL: J1.28, J2.28, R14.2
DA0: J1.35, J2.35, U5.50 (H_DA0)
DA1: J1.33, J2.33, U5.51 (H_DA1)
DA2: J1.36, J2.36, U5.49 (H_DA2)
DASP-: J1.39, J2.39, R21.2, U5.34 (T1)
DD0: J1.17, J2.17, U5.62 (H_DD0)
DD1: J1.15, J2.15, U5.64 (H_DD1)
DD2: J1.13, J2.13, U5.2 (H_DD2)
DD3: J1.11, J2.11, U5.5 (H_DD3)
DD4: J1.9, J2.9, U5.7 (H_DD4)
DD5: J1.7, J2.7, U5.11 (H_DD5)
DD6: J1.5, J2.5, U5.13 (H_DD6)
DD7: J1.3, J2.3, U5.15 (H_DD7)
DD8: J1.4, J2.4, U5.14 (H_DD8)
DD9: J1.6, J2.6, U5.12 (H_DD9)
DD10: J1.8, J2.8, U5.10 (H_DD10)
DD11: J1.10, J2.10, U5.6 (H_DD11)
DD12: J1.12, J2.12, U5.3 (H_DD12)
DD13: J1.14, J2.14, U5.1 (H_DD13)
DD14: J1.16, J2.16, U5.63 (H_DD14)
DD15: J1.18, J2.18, U5.61 (H_DD15)
DIOR-: J1.25, J2.25, U5.58 (H_DIOR_N)
DIOW-: J1.23, J2.23, U5.59 (H_DIOW_N)
DMACK-: J1.29, J2.29, U5.54 (H_DMACK_N)
DMARQ: J1.21, J2.21, R3.2, U5.60 (H_DMARQ)
GND: C16.2, C17.1, C18.2, C19.1, C20.2, C21.2, C22.1, C23.2, C24.1, J1.2, J1.19, J1.22, J1.24, J1.26, J1.30, J1.32, J1.40, J2.2, J2.19, J2.22, J2.24, J2.26, J2.30, J2.32, J2.40, J3.1 (MH1), J3.2 (MH2), J3.S1 (GND_1), J3.S4 (GND_2), J3.S7 (GND_3), R3.1, R11.1, R15.2, R19.1, R23.1, R26.1, U1.1 (GND), U5.8 (GND), U5.37 (T4), U5.38 (T5), U5.42 (GND), U5.57 (GND), U5.65 (GND)
INTRQ: J1.31, J2.31, R11.2, U5.53 (H_INTRQ)
IORDY: J1.27, J2.27, R8.2, U5.55 (H_IORDY)
LED-: U5.45 (UAO)
unnamed: C25.1, R22.1, R28.2, Y1.1
unnamed: C9.2, J3.S2 (A+)
unnamed: C10.2, J3.S3 (A-)
unnamed: C12.2, J3.S6 (B+)
unnamed: C11.2, J3.S5 (B-)
unnamed: R4.2, U5.21 (ATAIOS)
unnamed: R23.2, U5.26 (ISET)
unnamed: C19.2, R31.2, U5.17 (RST_N)
unnamed: R19.2, U5.33 (T0)
unnamed: R29.1, U5.43 (UAI)
PDIAG-: J1.34, J2.34, R16.1, U5.46 (H_PDIAG_N)
RESET-: J1.1, J2.1, U5.16 (H_RESET_N)
RX_N: C11.1, U5.28 (RX_M)
RX_P: C12.1, U5.27 (RX_P)
T2: U5.35 (T2)
T3: R1.1, U5.36 (T3)
T6: U5.39 (T6)
T7: R18.2, U5.40 (T7)
T8: R26.2, U5.52 (T8)
TX_N: C10.1, U5.31 (TX_M)
TX_P: C9.1, U5.32 (TX_P)
VAA: C13.1, C14.1, C15.1, FB1.2, U5.24 (VAA), U5.29 (VAA)
VSS: C13.2, C14.2, C15.2, C25.2, C26.2, U5.25 (VSS), U5.30 (VSS)
XTLIN: C26.1, R22.2, U5.22 (XTLIN/OSC), Y1.2
XTLOUT: R28.1, U5.23 (XTLOUT)

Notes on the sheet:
000 Device mode 100MB/s 001 Device mode 133MB/s 010 Device mode 150MB/s 110 Host mode 150MB/s CNFG0 internal pull down to 100K CNFG1 internal pull up to 100K CNFG2 internal pull down to 100K
VAA and VSS power supplies
xbox IDE connection
R24 : T6 Not installed, removed
T5 fix UDMA mode 1 fixes its UDMA mode 0 monitor set feature
Information about CNFG[0..2] and T[0..8] from \documents\asus_f70sl_rev_1.0_sch.pdf
R31 change from 5.6K to 1M
T3 T4 10 25MHz T3 T4 00 20MHz
Master device only.
DVD drive header
SATA connector
T5; On Startech connected to jumper pin 7 ACD
Configuration
T7 SATA mode 0 1.5Gbps 1 3.0Gbps
3V3 power supply
Marvell bridge IC
To find suitable tap point on xbox motherboard revisions
T6 power mode 0 disable 1 enable
1V2 power supply
Are capacitors or resistors better for reflections in high speed paired signals like these?
R1 : T3 From 4.7K to 10K
T0/T1 vendor ID
Oscillator
T2 0 disable SSC 1 enable SSC (internal pull-down)
Transfer rate
R27 : T2 Not installed, removed
T8 SIGNATURE FIS 0 transformer from registers 1 force bit4 to 1
Not sure which mode is selected? is it 011? Labels, values, traces checked and OK.

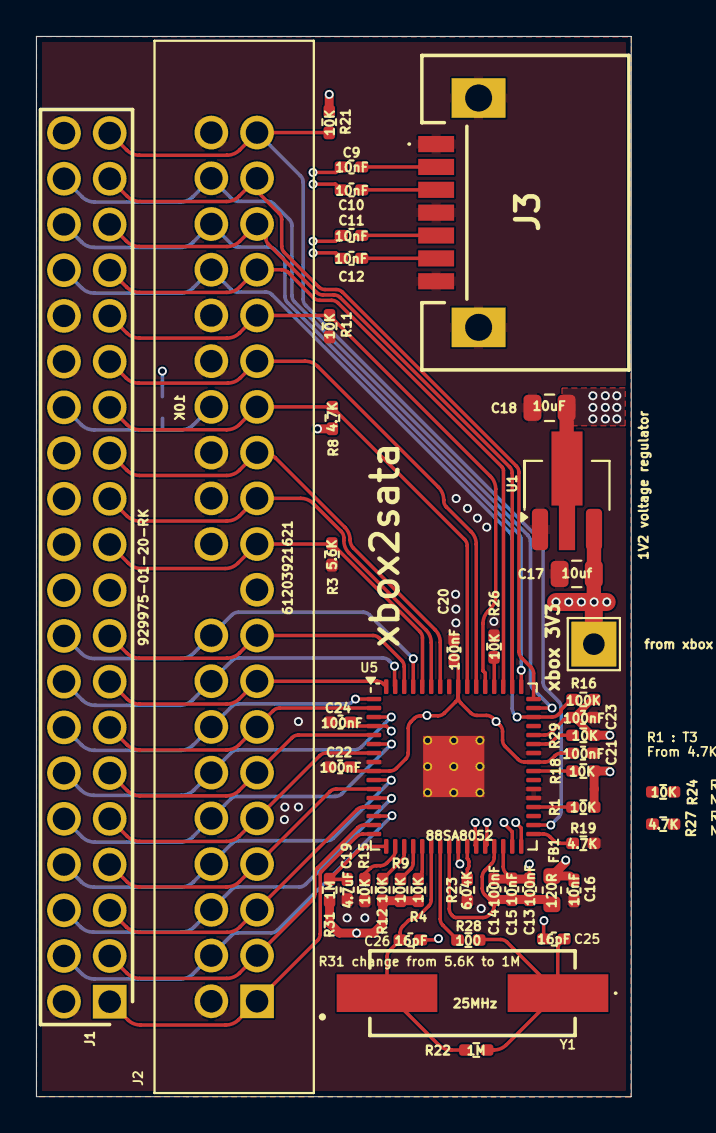
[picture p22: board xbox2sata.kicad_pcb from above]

Board: 4 copper layers, 33.0 x 58.9 mm, 47 parts (1 on the bottom side), 58 nets.

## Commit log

2024-03-20 Update README.md
    added questions about what is required from Startech pcb to xbox pcb.
2024-03-20 Images added
    Added v1.6 motherboard voltage readings image.
    Added screenshot of xbox2sata 3d layout.
2024-03-21 additions to xbox2sata proteus schematic
2024-03-21 Created KiCad project with 88SA symbol
    new KiCad project xbox2sata with Marvel 88SA symbol
    [xbox2sata.kicad_pcb, xbox2sata.kicad_sch]
2024-03-21 KIiCad symbols and footprints added
    Added symbols, footprints, 3d models for Marvel 88SA, SATA data socket and IDE socket for DVD drive cable.
    To try another 3d model for IDE socket.
    [61203921621_Download_IGS_61203921621_rev1.igs, 61203921621_Download_STP_61203921621_rev1.stp, 678008025.stp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]
2024-03-22 KiCad updates
    Crystal resonator added, 3d model for ide header fixed.
    [1761633-2.stp, 90151-2140.stp, ABLS-25.000MHZ-B4-F-T.stp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]
2024-03-22 PCB folder structure
    Created two sub folders in PCB; Proteus and KiCad and moved respective files into folders.
    [1761633-2.stp, 61203921621_Download_IGS_61203921621_rev1.igs, 61203921621_Download_STP_61203921621_rev1.stp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]
2024-03-24 KiCad updates
    Nets and some components added
    [xbox2sata.kicad_pcb, xbox2sata.kicad_sch]
2024-03-25 KiCad update
    Added to schematic and pcb
    [TLV1117LV12DCYR.stp, xbox2sata.kicad_pcb, xbox2sata.kicad_sch]
2024-03-27 Notes added to KiCad schematic
    Requests for checking routing and signals are correct.
    [xbox2sata.kicad_sch]
2024-04-01 ground cable point removed
    ground to xbox through ide header
    [xbox2sata.kicad_sch]
2024-06-26 slight changes to schematic
    [xbox2sata.kicad_pcb, xbox2sata.kicad_sch]
2024-06-27 1V2 regulator circuit corrected, all labels need correcting
    1V2 regulator circuit corrected, all labels need correcting
    [xbox2sata.kicad_sch]
2024-06-28 T0-8 updated, label changes
    Several cap and res labels changed, T0-8 config changed, layers.xcf saved with compression.
    [xbox2sata.kicad_sch]
2024-07-01 oscillator circuit corrected
    [xbox2sata.kicad_pcb, xbox2sata.kicad_sch]
2024-07-03 Variable voltage regulator changed to fixed 1V2
    Variable voltage regulator changed to fixed 1V2 regulator. L1 is a ferrite bead not a inductor.
    [xbox2sata.kicad_sch]
2024-07-08 IDE pins changes
    IDE pins 32 and 34 on xbox only connect to test points. Therefore connected to ground.
    [xbox2sata.kicad_sch]
2024-07-11 bill of matierals
    spreadsheet for bill of materials,
    IDE female socket changed to cheaper option,
    SATA socket changed to right angle, recommend by doofus.
    [61203921621_Download_IGS_61203921621_rev1.igs, 61203921621_Download_STP_61203921621_rev1.stp, 929975-01-20-RK.stp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]
2024-07-16 reset and csel correct circuit from startech
    10K resistor (R14) pull-up to 3V3 added to CSEL IDE pin 28
    4.7K resistor (R19) pull-down to ground on T0 U5 pin 33 to device as IDE master
    positive power supply icons changed from Global labels to power symbols
    [xbox2sata.kicad_pcb, xbox2sata.kicad_sch]
2024-07-19 Reset-Negative was not enabled
    Positive power supply icons changed from Global labels to Power symbols
    Via sizes changed to 0.3 and 0.5 mm for jlcpcb requirements
    Bill of materials updated
    Mouser shared basket created;
    https://www.mouser.co.uk/api/CrossDomain/GetContext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
    Datasheets added
    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
    [bill of materials.ods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]
2024-08-01 Two resistors removed, two component values changed
    R27 : T2
    Not installed, removed
    R1 : T3
    From 4.7K to 10K
    R24 : T6
    Not installed, removed
    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
    [xbox2sata v0.2.kicad_pcb, xbox2sata.kicad_pcb, xbox2sata.kicad_sch]
2024-08-25 why u not work!?!
    going back from start checking for errors, but I'm guessing the error lies with the IDE pull-up and down resistors and possibly the T0-8 configuration setup.
    [xbox2sata.kicad_sch]
